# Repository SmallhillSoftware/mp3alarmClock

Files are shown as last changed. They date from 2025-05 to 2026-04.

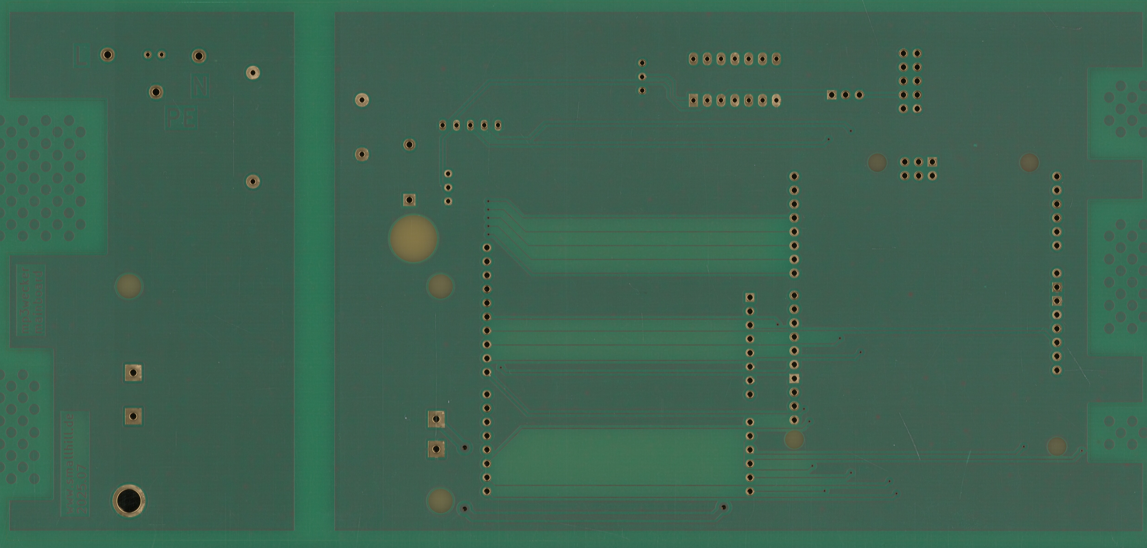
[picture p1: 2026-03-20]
pcb-layouts/mp3wecker_mainboard_endoberflaecheTop.jpg

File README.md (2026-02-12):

# mp3alarmClock
# S. Kleineberg / 2026                                  rev. (2025)1031 
***********************************************************************
The mp3alarmClock is an Arduino-Uno-based alarm clock that wakes you
up by playing 100 of your favourite MP3s stored on a Mico-SD-card.
The SD-card-handling and MP3-decoding and amplification is done using
an Adafruit-MP3-shield. The actual time is displayed on green 7-Segment-
LED-displays. The clock could be synchronized by a quarz crystal or
50Hz-power-frequency.
Details for the HW could be found at:
http://www.smallhill.de/html/hardware.html
***********************************************************************

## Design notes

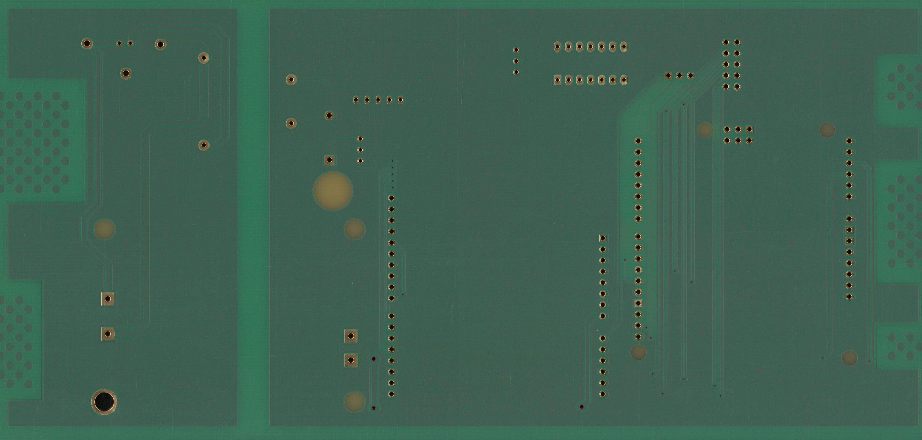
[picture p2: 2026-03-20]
pcb-layouts/mp3wecker_mainboard_endoberflaecheBottom.jpg

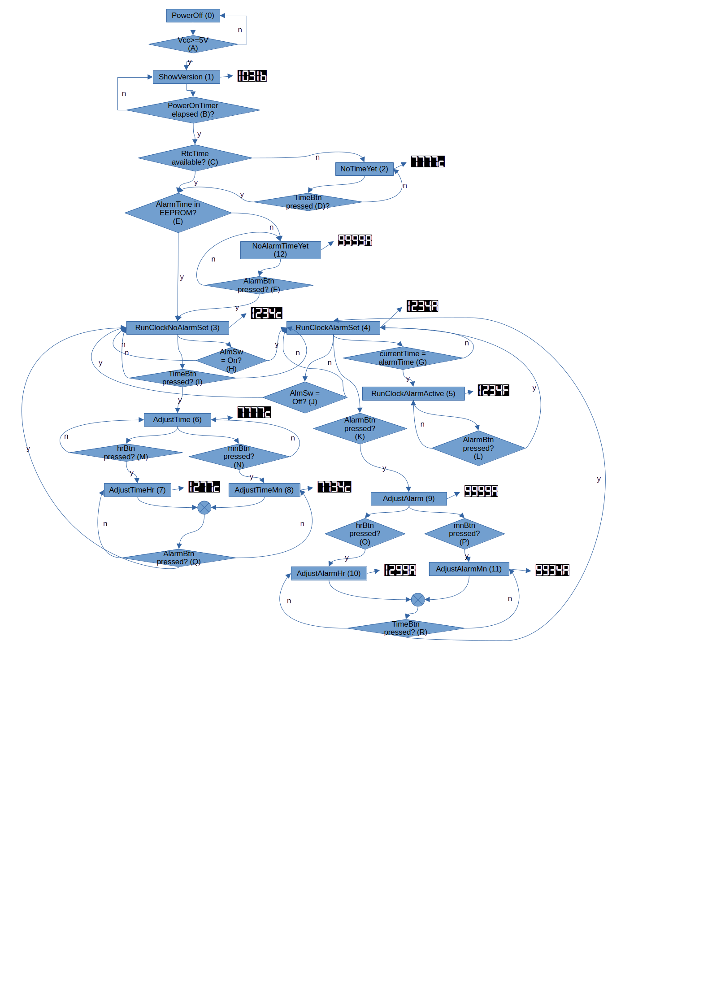
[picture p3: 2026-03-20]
documentation/statemachine_mp3wecker.png

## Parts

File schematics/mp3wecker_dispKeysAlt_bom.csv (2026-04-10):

# | Reference | Qty | Value | Footprint | DNP
1 | D1, D2, D3, D4, D5 | 5 | SC56-11GWA | mp3weckerLibrary:SA56kingbright
2 | D6, D7 | 2 | 3mmGN | LED_THT:LED_D3.0mm_IRBlack
3 | D8, D9 | 2 | 1N4148 | Diode_THT:D_DO-35_SOD27_P7.62mm_Horizontal
4 | J2 | 1 | Arduino | PCM_4ms_Connector:Pins_2x05_2.54mm_TH_Europower
5 | Q1, Q2, Q3, Q4, Q5, Q6 | 6 | BC337 | Package_TO_SOT_THT:TO-92L_HandSolder
6 | R1, R2, R3, R4, R5, R13, R14, R15 | 8 | 1k | Resistor_THT:R_Axial_DIN0207_L6.3mm_D2.5mm_P2.54mm_Vertical
7 | R6, R7, R8, R9, R10, R11 | 6 | 33k | Resistor_THT:R_Axial_DIN0207_L6.3mm_D2.5mm_P2.54mm_Vertical
8 | R12 | 1 | 250R | Resistor_THT:R_Axial_DIN0207_L6.3mm_D2.5mm_P2.54mm_Vertical
9 | R16, R17, R18, R19, R20, R21, R23 | 7 | 220R | Resistor_THT:R_Axial_DIN0207_L6.3mm_D2.5mm_P2.54mm_Vertical
10 | S1 | 1 | Alarm | r8c13_consCounter2:RACON12
11 | S2 | 1 | Time | r8c13_consCounter2:RACON12
12 | S3 | 1 | Hour+ | r8c13_consCounter2:RACON12
13 | S4 | 1 | Min+ | r8c13_consCounter2:RACON12
14 | SW1 | 1 | SW_Push_SPDT | PCM_4ms_Switch:Switch_Toggle_SPDT_SubMini
15 | U1 | 1 | 4511 | Package_DIP:CERDIP-16_W7.62mm_SideBrazed_LongPads_Socket
16 | U3 | 1 | MCP23008-xP | Package_DIP:DIP-18_W7.62mm
17 | U9 | 1 | 4017 | Package_DIP:DIP-16_W7.62mm_Socket_LongPads

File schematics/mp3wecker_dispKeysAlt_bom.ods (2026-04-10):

Referenz | Menge | Typ
D1, D2, D3, D4, D5 | 5 | SC56-11GWA
D6, D7 | 2 | LED, 3mm GN
D8, D9 | 2 | 1N4148
J2 | 1 | Arduino-Connector
Q1, Q2, Q3, Q4, Q5, Q6 | 6 | BC337
R1, R2, R3, R4, R5, R13, R14, R15 | 8 | 1k
R6, R7, R8, R9, R10, R11 | 6 | 33k
R12 | 1 | 250R
R16, R17, R18, R19, R20, R21, R23 | 7 | 220R
S1, S2, S3, S4 | 1 | RACON12
SW1 | 1 | SW_Push_SPDT
U1 | 1 | 4511, DIP-16
U3 | 1 | MCP23008-xP
U9 | 1 | 4017, DIP16

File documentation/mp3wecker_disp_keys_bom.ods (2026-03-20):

Referenz | Menge | Typ
D1, D2, D3, D4, D5 | 5 | SA56-11GWA
D6, D7 | 2 | LED, 3mmGN
J2 | 1 | Arduino-Connector
Q1, Q2, Q3, Q4, Q5, Q6 | 6 | BC327
R1, R2, R3, R4, R5, R15 | 6 | 1k
R6, R7, R8, R9, R10, R11 | 6 | 33k
R12, R13, R14 | 3 | 250R
RV1 | 1 | 50k, Bourns 3296W
S1, S2, S3, S4 | 1 | RACON12
SW1 | 1 | SW_Push_SPDT
U1 | 1 | D346D
U3 | 1 | MCP23008-xP
U9 | 1 | GAL16V8

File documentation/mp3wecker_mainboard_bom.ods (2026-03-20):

Referenz | Menge | Typ
A1 | 1 | Connector MP3-Shield
A2 | 1 | Connector Arduino UNO R3
D1 | 1 | 1N4001
J1, J3 | 2 | Conn_01x01_Socket
J2 | 1 | Arduino
J4 | 1 | N
J5 | 1 | ODROID-RTC
JP1 | 1 | 3er Jumper
JP2 | 1 | 2er Jumper
R1, R2 | 2 | 10k
T1 | 1 | Transformer_1P_1S
U1 | 1 | 4093, DIP14
U2 | 1 | EPS-15-7.5

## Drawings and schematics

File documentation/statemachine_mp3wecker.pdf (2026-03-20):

1031b

7777c

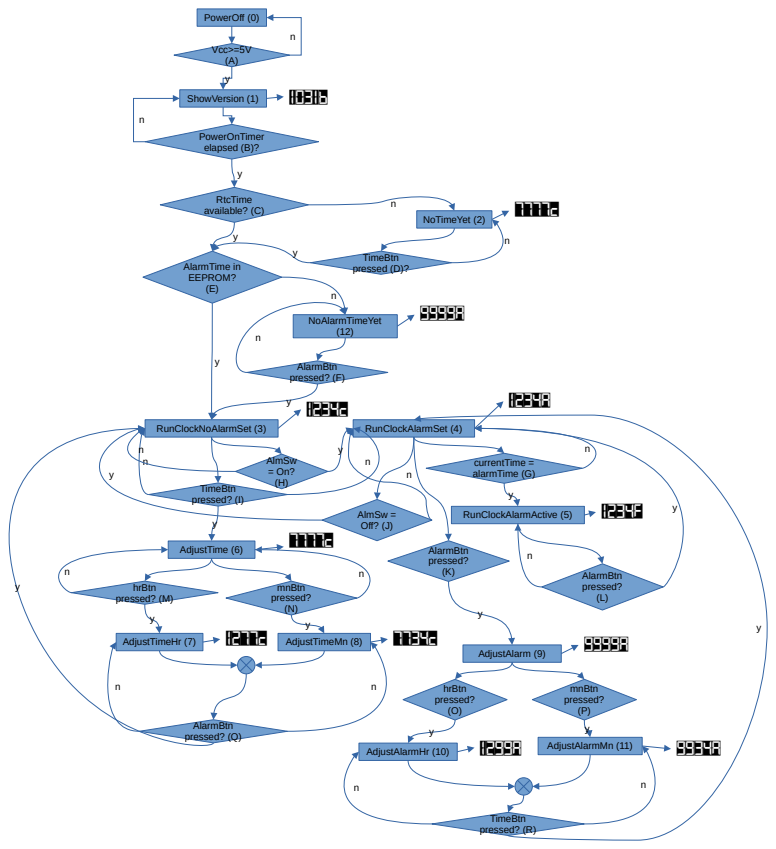
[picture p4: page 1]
PowerOff (0); ShowVersion (1); NoTimeYet (2); RunClockNoAlarmSet (3); AdjustTimeHr (7); AdjustTimeMn (8); AdjustAlarmHr (10); AdjustAlarmMn (11); RunClockAlarmSet (4); RunClockAlarmActive (5); Vcc>=5V (A); PowerOnTimer elapsed (B)?; TimeBtn pressed (D)?; AlarmBtn pressed? (F); AlarmTime in EEPROM? (E); RtcTime available? (C); AlmSw = On? (H); currentTime = alarmTime (G); AdjustTime (6); TimeBtn pressed? (I); hrBtn pressed? (M); mnBtn pressed? (N); AlarmBtn pressed? (Q); AlarmBtn pressed? (K)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

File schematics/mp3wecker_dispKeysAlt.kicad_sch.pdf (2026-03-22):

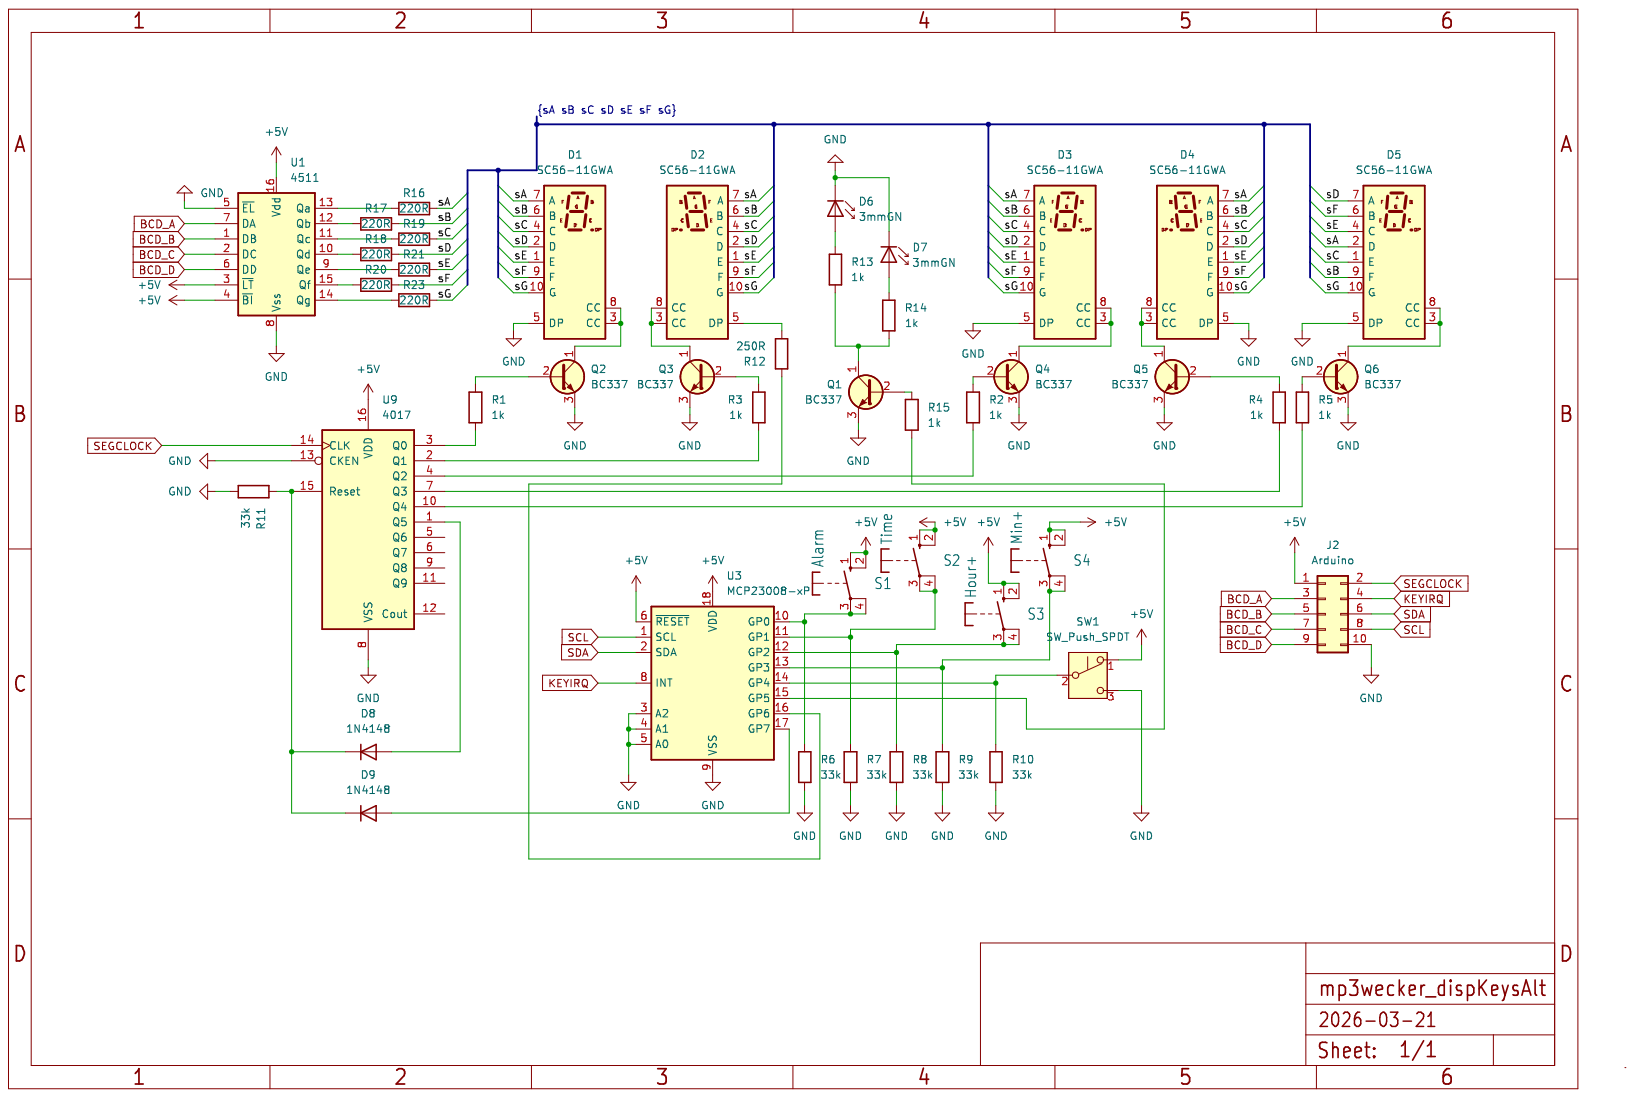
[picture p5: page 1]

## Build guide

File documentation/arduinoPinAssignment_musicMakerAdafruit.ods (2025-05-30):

valid for Arduino: | Uno Rev3
valid for shield: | Music Maker (Adafruit)
pin name | specific pin function | used pin direction for Arduino | shield pin name | explanation | comment
IO0 | RxD (UART)
IO1 | TxD (UART)
IO2 | INT0
IO3 | INT1 | input | DREQ (VS1053) | VS1053 data request IRQ
IO4 |  | output | CCS (SD) | SD card chip select
IO5
IO6 |  | output | DCS (VS1053) | VS1053 data select
IO7 |  | output | MCS (VS1053) | VS1053 chip select
IO8
IO9
IO10 | SS (SPI)
IO11 | MOSI (SPI) | output | MOSI (SD, VS1053)
IO12 | MISO (SPI) | input | MISO (SD, VS1053)
IO13 | SCK (SPI) | output | SCK (SD, VS1053)
AD0
AD1
AD2
AD3
AD4 | SDA (I2C)
AD5 | SCL (I2C)

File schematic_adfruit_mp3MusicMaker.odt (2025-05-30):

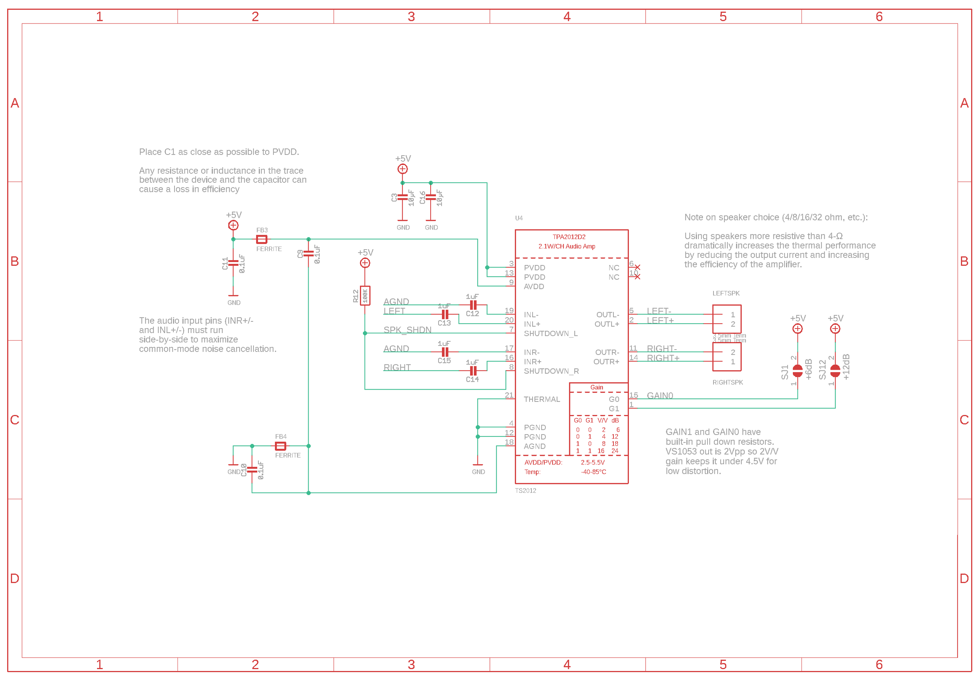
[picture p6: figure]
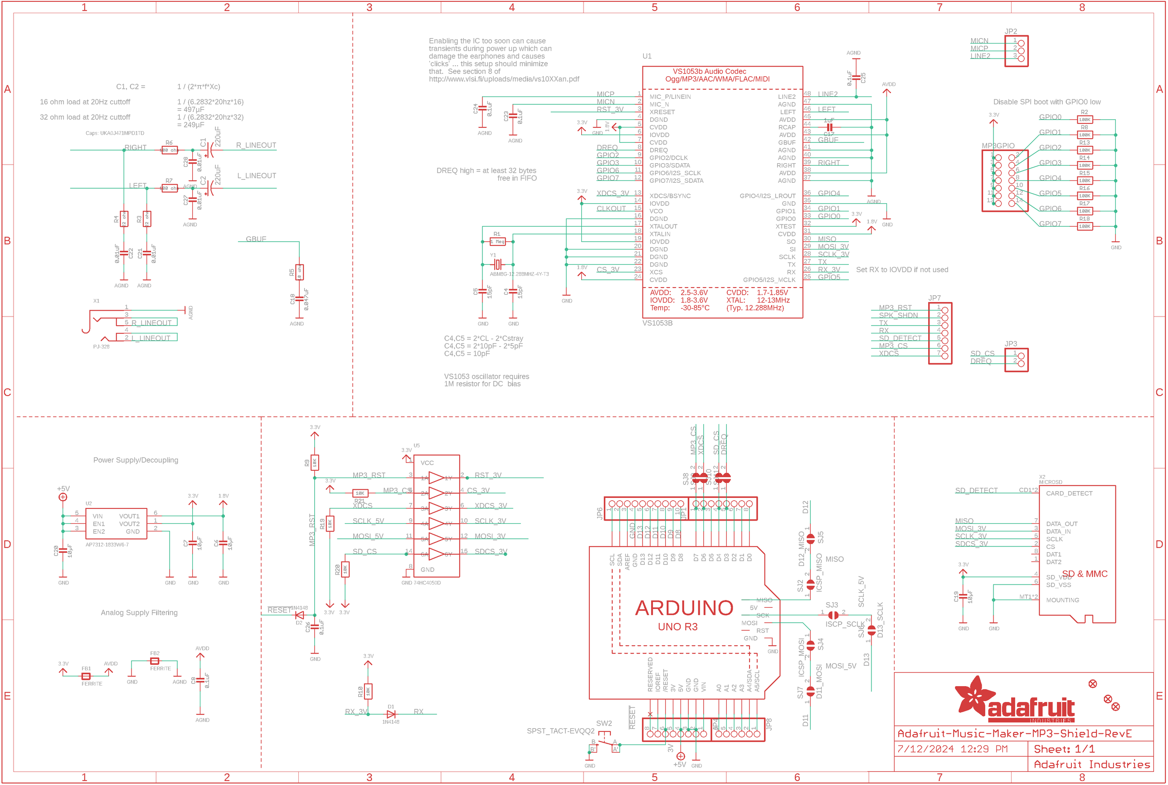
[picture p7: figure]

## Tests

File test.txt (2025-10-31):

Donnerstag 02.10.25 21:01 nach Smartphone Uhr eingestellt
ohne delay(100) in der loop
mit 61536 timer reload wert (2^16-4000).
Sonntag 05.10.25 18:30 Anzeige Uhr 17:09 also 90 Minuten zu spaet.
Neue SW mit Timerreloadwert 61540
Synchronisiert mit CD-Wecker um 18:37 am 05.10.25.
Aendert kaum etwas. Ist nach 1 Tag mindestens 20 min zu spaet.
Neue SW 2025.10.28 mit 5ms Timerwert nach
https://deepbluembedded.com/arduino-timer-calculator-code-generator/
Synchronisiert mit CD-Wecker am 28.10.25 21:43 (mp3wecker auf 21:45)
CD-Wecker am 29.10.25 21:02 (mp3Wecker auf 20:52)
Fehler -0.85%. Aus 5ms oder 5000µs werden damit 4957.1122µs. Timer Reload Wert 55621
SW 29.10.25
Synchronisiert mit CD-Wecker am 29.10.25 21:27 (mp3wecker auf 21:27)
Zeigt am 30.10.25 21:46 auf dem cdWecker und 21:48 auf dem mp3Wecker

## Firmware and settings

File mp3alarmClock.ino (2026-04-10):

/******************************************************************************
 * MP3ALARMCLOCK
 * Drives a 4-digit-7-Segment-LED-display, implements a quarz- or net-frequency
 * synced clock with possibility to set an alarm time
 * Plays MP3-files between 00.mp3 and 99.mp3 when the alarm time fires
 * www.smallhill.de 2025
 ******************************************************************************/
#include <EEPROM.h>
#include <SD.h>
#include <SPI.h>
#include <Adafruit_VS1053.h>
#include "MCP23008.h"

/******************************************************************************
 * globale Defines
 ******************************************************************************/
// These are the pins used for the music maker shield
#define VS1053RESETpin -1      // VS1053 reset pin (unused!)
#define VS1053CSpin     7      // VS1053 chip select pin (output)
#define VS1053DCSpin    6      // VS1053 Data/command select pin (output)
// These are common pins between breakout and shield
#define SDCARDCSpin     4      // Card chip select pin
// DREQ should be an Int pin, see http://arduino.cc/en/Reference/attachInterrupt
#define VS1053DREQpin   3      // VS1053 Data request, ideally an Interrupt pin
//#define D_RELOADvalFor20ms 25536
//#define D_RELOADvalFor2ms 61540
#define D_RELOADvalFor5ms 55621 //4957µs
#define D_mp3Clock 0
#define D_4511_4017 1
#if (D_mp3Clock)
  //pinning for for MP3-clock
  #define D_SEGCLOCKpin 0
  #define D_BCDApin 1
  #define D_BCDBpin 9
  #define D_BCDCpin 10
  #define D_BCDDpin A1
#else
  //pinning for Arduino Uno Adapter but not for MP3-clock
  #define D_SEGCLOCKpin 10
  #define D_BCDApin 1
  #define D_BCDBpin 2
  #define D_BCDCpin 9
  #define D_BCDDpin 0
#endif
#if (D_4511_4017)
  #define D_DISPSTATECLK 7 //L
  #define D_DISPSTATEALM 3 //E
  #define D_DISPSTATEACT 9 //stilisiertes Y
  #define D_DISPSTATEVER 4 //stilisiertes V
  #define D_DISPSTATE_TST2 5 //S
  #define D_DISPSTATE_TST3 5 //S
#else
  #define D_DISPSTATECLK 12 //C
  #define D_DISPSTATEALM 10 //A
  #define D_DISPSTATEACT 15 //F
  #define D_DISPSTATEVER 11 //b
  #define D_DISPSTATE_TST2 13 //d
  #define D_DISPSTATE_TST3 14 //e
#endif

#define D_PowerOff_State             0
#define D_ShowVersion_State          1
#define D_noTimeYet_State            2
#define D_RunClockNoAlarmSet_State   3
#define D_RunClockAlarmSet_State     4
#define D_RunClockAlarmActive_State  5
#define D_AdjustTime_State           6
#define D_AdjustTimeHr_State         7
#define D_AdjustTimeMn_State         8
#define D_AdjustAlarm_State          9
#define D_AdjustAlarmHr_State       10
#define D_AdjustAlarmMn_State       11
#define D_noAlarmTimeYet_State      12

//eeprom addresses
#define D_eepromAdrFileHandling      0
#define D_eepromAdrAlarmHr           1
#define D_eepromAdrAlarmMin          2


/******************************************************************************
 * globale Variablen
 ******************************************************************************/
Adafruit_VS1053_FilePlayer musicPlayer = 
  // create shield-example object!
  Adafruit_VS1053_FilePlayer(VS1053RESETpin, VS1053CSpin, VS1053DCSpin, VS1053DREQpin, SDCARDCSpin);

byte BT_mk_month = 4;
byte BT_mk_day = 10;

bool BL_setupFinished = false;

//clock variables
byte BT_currHr = 12;
byte BT_currMin = 34;
//alarm variables
byte BT_alarmHr = 0;
byte BT_alarmMin = 0;
//display variables
byte BT_dispHr = 0;
byte BT_dispMin = 0;
byte BT_dispState = 0;
//unsigned int UI_twentyMSecs = 0;
//unsigned int UI_twoMSecs = 0;
unsigned int UI_fiveMSecs = 0;
unsigned int UI_seconds = 0;

//display variables
int INT_digitToUpdate = 0;

//i2c-port-extender
MCP23008 MCP(0x20);

#define D_ALMBUTTON     0
#define D_SETTIMEBUTTON 1
#define D_HOURINCBUTTON 2
#define D_MININCBUTTON  3
#define D_ALMONBUTTON   4
#define D_MID_LEDS_OUT  5
#define D_D2_DP_OUT     6
#define D_OE_RESET_OUT  7
byte BT_buttonState = 0;
byte BT_prevButtonState = 0;
bool BL_midLedState = false;
unsigned long UL_currentButtonMillis = 0;
unsigned long UL_previousButtonMillis = 0;
#define D_minButtonPressDurationInMs 100

//state machine
byte BT_State = D_PowerOff_State;
byte BT_prevState;

//get time from battery backed-up RTC
bool B_timeFromRtc;
unsigned char UC_hourFromRtc = 0;
unsigned char UC_minuteFromRtc = 0;

//eeprom variables
unsigned char UC_filenumber = 0;
bool B_fileNrInEeprom;
unsigned char UC_storedAlarmHr  = 0;
bool B_alarmHrInEeprom;
unsigned char UC_storedAlarmMin = 0;
bool B_alarmMinInEeprom;

//file name for MP3-files to play in 8.3-format
char C_filename[12];

//indicator if currently MP3s are played
bool B_playMusic = false;

#define D_invertedAmpVolume 45

/******************************************************************************
 * Funktionen
 ******************************************************************************/
void initSegmentCounter(void)
{
  digitalWrite(D_SEGCLOCKpin, LOW);
  MCP.write1(D_OE_RESET_OUT, HIGH);
  #if (D_4511_4017)
    delay(100);
  #else
    for (int i=0; i<5; i++)
    {
      //Generiere 5 Pulse um alle D-flip-flops durchzutakten
      digitalWrite(D_SEGCLOCKpin, LOW);
      delay(50);
      digitalWrite(D_SEGCLOCKpin, HIGH);
      delay(50);
    }
  #endif
  //Reset fuer Segment-Counter zuruecknehmen
  MCP.write1(D_OE_RESET_OUT, LOW);
}


void writeBcdToSegPins(byte BT_givenNumber, byte BT_upperNibble)
{
byte BT_number;
  if (BT_upperNibble == 1)
  {
    BT_number = (byte)(BT_givenNumber / 10);
  }
  else if (BT_upperNibble == 2)
  {
    BT_number = BT_givenNumber;
  }
  else
  {
    BT_number = (byte)(BT_givenNumber % 10);
  }
  if ((BT_number & 1) == 1)
  {
    digitalWrite(D_BCDApin, HIGH);
  }
  else
  {
    digitalWrite(D_BCDApin, LOW);
  }
  if ((BT_number & 2) == 2)
  {
    digitalWrite(D_BCDBpin, HIGH);
  }
  else
  {
    digitalWrite(D_BCDBpin, LOW);
  }
  if ((BT_number & 4) == 4)
  {
    digitalWrite(D_BCDCpin, HIGH);
  }
  else
  {
    digitalWrite(D_BCDCpin, LOW);
  }
  if ((BT_number & 8) == 8)
  {
    digitalWrite(D_BCDDpin, HIGH);
  }
  else
  {
    digitalWrite(D_BCDDpin, LOW);
  }
}


void setup()
{
byte bt_eepromData;
  //Clock pin fuer Segment-Counter als Ausgang und Low setzen
  pinMode(D_SEGCLOCKpin, OUTPUT);
  digitalWrite(D_SEGCLOCKpin, LOW);
  //BCD-pins fuer D346 als Ausgaenge setzen
  pinMode(D_BCDApin, OUTPUT);
  digitalWrite(D_BCDApin, LOW);
  pinMode(D_BCDBpin, OUTPUT);
  digitalWrite(D_BCDBpin, LOW);
  pinMode(D_BCDCpin, OUTPUT);
  digitalWrite(D_BCDCpin, LOW);
  pinMode(D_BCDDpin, OUTPUT);
  digitalWrite(D_BCDDpin, LOW);

  //get file number from eeprom
  bt_eepromData = EEPROM.read(D_eepromAdrFileHandling);
  if ((bt_eepromData & 0x80) == 0x80)
  {
    B_fileNrInEeprom = true;
    UC_filenumber = (bt_eepromData & 0x7F);
    if (UC_filenumber > 99)
    {
      UC_filenumber = 99;
    }
  }
  else
  {
    B_fileNrInEeprom = false;
    UC_filenumber = 0;
  }

  //get alarm hour from eeprom
  bt_eepromData = EEPROM.read(D_eepromAdrAlarmHr);
  if ((bt_eepromData & 0x80) == 0x80)
  {
    B_alarmHrInEeprom = true;
    UC_storedAlarmHr = (bt_eepromData & 0x7F);
    if (UC_storedAlarmHr > 23)
    {
      B_alarmHrInEeprom = false;
      UC_storedAlarmHr = 0;
    }
  }
  else
  {
    B_alarmHrInEeprom = false;
    UC_storedAlarmHr = 0;
  }

  //get alarm minute from eeprom
  bt_eepromData = EEPROM.read(D_eepromAdrAlarmMin);
  if ((bt_eepromData & 0x80) == 0x80)
  {
    B_alarmMinInEeprom = true;
    UC_storedAlarmMin = (bt_eepromData & 0x7F);
    if (UC_storedAlarmMin > 59)
    {
      B_alarmMinInEeprom = false;
      UC_storedAlarmMin = 0;
    }
  }
  else
  {
    B_alarmMinInEeprom = false;
    UC_storedAlarmMin = 0;
  }

  //get time from battery backed-up RTC
  B_timeFromRtc = false;
  
  //Alle Interrupts deaktivieren
  noInterrupts();
  //
  INT_digitToUpdate = 0;
  //Bits von TCCR1A und TCCR1B loeschen
  TCCR1A = 0;
  TCCR1B = 0;
  //Laden des Zaehlerwertes
  TCNT1 = D_RELOADvalFor5ms;
  //Prescaler: 8
  TCCR1B |= (1 << CS11);
  //Enable timer overflow interrupt
  TIMSK1 |= (1 << TOIE1);
  //Alle Interrupts aktivieren
  interrupts();
      
  //MP3-Decoder initialisieren
  musicPlayer.begin();
  
  //SD-Karte initialisieren
  //SD_CS als parameter übergeben, da hier ChipSelect anders belegt
  SD.begin(SDCARDCSpin);
  
  // Set volume for left, right channels. lower numbers == louder volume!
  musicPlayer.setVolume(D_invertedAmpVolume,D_invertedAmpVolume);

  // This option uses a pin interrupt. No timers required! But DREQ
  // must be on an interrupt pin. For Uno/Duemilanove/Diecimilla
  // that's Digital #2 or #3
  // See http://arduino.cc/en/Reference/attachInterrupt for other pins
  // *** This method is preferred
  musicPlayer.useInterrupt(VS1053_FILEPLAYER_PIN_INT);

  Wire.begin();
  Wire.setWireTimeout(3000 /* us */, true /* reset_on_timeout */);
  MCP.begin(false);

  while(!(MCP.isConnected()))
  {
    //wait to be connected
    //verbindet aber nicht
  }
  
  //MCP.pinMode8(0x1F); //upper 3 bits are outputs
  MCP.pinMode1(D_ALMBUTTON, INPUT);
  MCP.pinMode1(D_SETTIMEBUTTON, INPUT);
  MCP.pinMode1(D_HOURINCBUTTON, INPUT);
  MCP.pinMode1(D_MININCBUTTON, INPUT);
  MCP.pinMode1(D_ALMONBUTTON, INPUT);
  MCP.pinMode1(D_MID_LEDS_OUT, OUTPUT);
  MCP.pinMode1(D_D2_DP_OUT, OUTPUT);
  MCP.pinMode1(D_OE_RESET_OUT, OUTPUT);
  
  MCP.setPolarity(D_ALMBUTTON, 0);
  MCP.setPolarity(D_SETTIMEBUTTON, 0);
  MCP.setPolarity(D_HOURINCBUTTON, 0);
  MCP.setPolarity(D_MININCBUTTON, 0);
  MCP.setPolarity(D_ALMONBUTTON, 0);
  MCP.setPolarity(D_MID_LEDS_OUT, 0);
  MCP.setPolarity(D_D2_DP_OUT, 0);
  MCP.setPolarity(D_OE_RESET_OUT, 0);

  MCP.setPullup(D_ALMBUTTON, 0);
  MCP.setPullup(D_SETTIMEBUTTON, 0);
  MCP.setPullup(D_HOURINCBUTTON, 0);
  MCP.setPullup(D_MININCBUTTON, 0);
  MCP.setPullup(D_ALMONBUTTON, 0);
  MCP.setPullup(D_MID_LEDS_OUT, 0);
  MCP.setPullup(D_D2_DP_OUT, 0);
  MCP.setPullup(D_OE_RESET_OUT, 0);
  
  initSegmentCounter(); //reset segment counter in GAL

  MCP.write1(D_MID_LEDS_OUT, HIGH); //klappt
  MCP.write1(D_D2_DP_OUT, HIGH);
  
  //signalize that the setup routine is finished
  BL_setupFinished = true;
}


ISR(TIMER1_OVF_vect)
{
  //START EXT-PIN-COUNT-IRQ
  //code to be executed when setup-routine is finished only
  if (BL_setupFinished)
  {
    //1sec passed
    if (UI_fiveMSecs == 200)
    {
      UI_fiveMSecs = 0;
      UI_seconds++;
      if (BL_midLedState == false)
      {
        BL_midLedState = true;
      }
      else
      {
        BL_midLedState = false;
      }
    }
    //1 minute passed, 200 occurrences of 5ms = 1sec and 60 of them means 1 min
    if (UI_seconds == 60)
    {
      UI_seconds = 0;
      if (BT_currMin < 59)
      {
        BT_currMin++;
      } //if (BT_currMin < 59)
      else
      {
        BT_currMin = 0;
        if (BT_currHr < 23)
        {
          BT_currHr++;
        } //if (BT_currHr < 23)
        else
        {
          BT_currHr = 0;
        } //else of if (BT_currHr < 23)
      } //else of if (BT_currMin < 59)
    } //if (UI_twoMSecs == (500 * 60))

    //write value to port pin
    digitalWrite(D_SEGCLOCKpin, LOW);
    if (INT_digitToUpdate == 0)
    {
      #if (D_4511_4017)
        writeBcdToSegPins(BT_dispHr, 0);
      #else
        writeBcdToSegPins(BT_dispHr, 1);
      #endif
      INT_digitToUpdate = 1;
    } //if (INT_digitToUpdate == 0)
    else if (INT_digitToUpdate == 1)
    {
      #if (D_4511_4017)
        writeBcdToSegPins(BT_dispMin, 1);
      #else
        writeBcdToSegPins(BT_dispHr, 0);
      #endif
      INT_digitToUpdate = 2;
    } //else if (INT_digitToUpdate == 1)
    else if (INT_digitToUpdate == 2)
    {
      #if (D_4511_4017)
        writeBcdToSegPins(BT_dispMin, 0);
      #else
        writeBcdToSegPins(BT_dispMin, 1);
      #endif
      INT_digitToUpdate = 3;
    } //else if (INT_digitToUpdate == 2)
    else if (INT_digitToUpdate == 3)
    {
      #if (D_4511_4017)
        writeBcdToSegPins(BT_dispState, 2);
      #else
        writeBcdToSegPins(BT_dispMin, 0);
      #endif
      INT_digitToUpdate = 4;
    } //else if (INT_digitToUpdate == 3)
    else if (INT_digitToUpdate == 4)
    {
      #if (D_4511_4017)
        writeBcdToSegPins(BT_dispHr, 1);
      #else
        writeBcdToSegPins(BT_dispState, 2);
      #endif
      INT_digitToUpdate = 0;
    } //else if (INT_digitToUpdate == 4)
    //write value to port pin
    digitalWrite(D_SEGCLOCKpin, HIGH);
    //
    UI_fiveMSecs++;
  } //if (BL_setupFinished)
  //reload counter value to make the IRQ firing again, always necessary independent from setup finished or not
  TCNT1 = D_RELOADvalFor5ms;
  //END EXT-PIN-COUNT-IRQ  
}

void loop()
{
unsigned int cntr = 0;
//build file name
sprintf(C_filename, "/%02d.mp3", UC_filenumber);
  
byte bt_eepromData;
  if (BL_midLedState == true)
  {
    MCP.write1(D_D2_DP_OUT, LOW);
  }
  else
  {
    MCP.write1(D_D2_DP_OUT, HIGH);
  }
  //read in buttons
  UL_currentButtonMillis = millis();
  BT_buttonState = 0;
  if ((UL_currentButtonMillis - UL_previousButtonMillis) >= D_minButtonPressDurationInMs)
  {
    if (MCP.read1(D_ALMBUTTON) == HIGH)
    {
      BT_buttonState = BT_buttonState | (byte)(((byte)(1 << D_ALMBUTTON)) & 0xFF);
    }
    if (MCP.read1(D_SETTIMEBUTTON) == HIGH)
    {
      BT_buttonState = BT_buttonState | (byte)(((byte)(1 << D_SETTIMEBUTTON)) & 0xFF);
    }
    if (MCP.read1(D_HOURINCBUTTON) == HIGH)
    {
      BT_buttonState = BT_buttonState | (byte)(((byte)(1 << D_HOURINCBUTTON)) & 0xFF);
    }
    if (MCP.read1(D_MININCBUTTON) == HIGH)
    {
      BT_buttonState = BT_buttonState | (byte)(((byte)(1 << D_MININCBUTTON)) & 0xFF);
    } 
    //update time stamp for pressing
    UL_previousButtonMillis += D_minButtonPressDurationInMs;
  } //end of if ((UL_currentButtonMillis - UL_previousButtonMillis) >= D_minButtonPressDurationInMs)
  if (MCP.read1(D_ALMONBUTTON) == HIGH)
  {
    BT_buttonState = BT_buttonState | (byte)(((byte)(1 << D_ALMONBUTTON)) & 0xFF);
  }
  
  //state machine
  switch (BT_State)
  {
    case D_PowerOff_State:
      BT_prevState = BT_State; //store previous state
      BT_State = D_ShowVersion_State;
      break; //D_PowerOff_State
    case D_ShowVersion_State:
      BT_dispHr = BT_mk_month;
      BT_dispMin = BT_mk_day;
      BT_dispState = D_DISPSTATEVER;
      delay(3000); //condition to change to next state
      if (B_timeFromRtc == true)
      {
        if ((B_alarmHrInEeprom == true) && (B_alarmMinInEeprom == true))
        {
          BT_State = D_RunClockNoAlarmSet_State;
        }
        else
        {
          BT_State = D_noAlarmTimeYet_State;
        }
      }
      else
      {
        BT_State = D_noTimeYet_State;
      }
      break; //D_ShowVersion_State
    case D_noTimeYet_State:
      BT_dispHr = 77;
      BT_dispMin = 77;
      BT_dispState = D_DISPSTATECLK;
      if ((BT_buttonState & (1 << D_SETTIMEBUTTON)) == (1 << D_SETTIMEBUTTON))
      {
        if ((B_alarmHrInEeprom == true) && (B_alarmMinInEeprom == true))
        {
          BT_State = D_RunClockNoAlarmSet_State;
        }
        else
        {
          BT_State = D_noAlarmTimeYet_State;
        }
      }
      break; //D_noTimeYet_State
    case D_noAlarmTimeYet_State:
      BT_dispHr = 99;
      BT_dispMin = 99;
      BT_dispState = D_DISPSTATEALM;
      if ((BT_buttonState & (1 << D_ALMBUTTON)) == (1 << D_ALMBUTTON))
      {
        BT_State = D_RunClockNoAlarmSet_State;
      }
      break; //D_noAlarmTimeYet_State
    case D_RunClockNoAlarmSet_State:
      BT_dispHr = BT_currHr;
      BT_dispMin = BT_currMin;
      BT_dispState = D_DISPSTATECLK;
      //wenn ich diese Bedingung rausnehme dann wechselt er nicht mehr in den Einstellmodus
      //wenn ich dann aber den Alarmzustand aktiviere wechselt er in den Einstellmodus und
      //alles blinkt
      if ((BT_buttonState & (1 << D_SETTIMEBUTTON)) == (1 << D_SETTIMEBUTTON))
      {
        BT_prevState = BT_State; //store previous state
        BT_State = D_AdjustTime_State;
      }
      else if ((BT_buttonState & (1 << D_ALMONBUTTON)) == (1 << D_ALMONBUTTON))
      {
        BT_State = D_RunClockAlarmSet_State;
      }
      break; //D_RunClockNoAlarmSet_State
    case D_RunClockAlarmSet_State:
      BT_dispHr = BT_currHr;
      BT_dispMin = BT_currMin;
      BT_dispState = D_DISPSTATEALM;
      if ((BT_currHr == BT_alarmHr) && (BT_currMin == BT_alarmMin))
      {
        BT_State = D_RunClockAlarmActive_State;
      }
      else if ((BT_buttonState & (1 << D_ALMBUTTON)) == (1 << D_ALMBUTTON))
      {
        BT_prevState = BT_State; //store previous state
        BT_State = D_AdjustAlarm_State; 
      }
      else if (!((BT_buttonState & (1 << D_ALMONBUTTON)) == (1 << D_ALMONBUTTON)))
      {
        BT_State = D_RunClockNoAlarmSet_State;
      }
      break; //D_RunClockAlarmSet_State
    case D_RunClockAlarmActive_State:
      BT_dispHr = BT_currHr;
      BT_dispMin = BT_currMin;
      BT_dispState = D_DISPSTATEACT;
      //play mp3s
      if ((BT_buttonState & (1 << D_ALMBUTTON)) == (1 << D_ALMBUTTON))
      {
        bt_eepromData = UC_filenumber + 0x80;
        EEPROM.update(D_eepromAdrFileHandling, bt_eepromData);
        BT_State = D_RunClockAlarmSet_State;
      }
      break; //D_RunClockAlarmActive_State
    case D_AdjustTime_State:
      BT_dispHr = 77;
      BT_dispMin = 77;
      BT_dispState = D_DISPSTATECLK;
      if ((BT_buttonState & (1 << D_HOURINCBUTTON)) == (1 << D_HOURINCBUTTON))
      {
        BT_State = D_AdjustTimeHr_State;
      }
      else if ((BT_buttonState & (1 << D_MININCBUTTON)) == (1 << D_MININCBUTTON))
      {
        BT_State = D_AdjustTimeMn_State;
      }
      else if ((BT_buttonState & (1 << D_ALMBUTTON)) == (1 << D_ALMBUTTON))
      {
        if (BT_prevState == D_RunClockAlarmSet_State)
        {
          BT_State = D_RunClockAlarmSet_State;
        }
        else
        {
          BT_State = D_RunClockNoAlarmSet_State;
        }
      }
      break; //D_AdjustTime_State
    case D_AdjustTimeHr_State:
      BT_dispHr = BT_currHr;
      BT_dispMin = 77;
      BT_dispState = D_DISPSTATECLK;
      if ((BT_buttonState & (1 << D_HOURINCBUTTON)) == (1 << D_HOURINCBUTTON))
      {
        if (BT_currHr < 23)
        {
          BT_currHr++;
        }
        else
        {
          BT_currHr = 0;
        }
      }
      else if ((BT_buttonState & (1 << D_SETTIMEBUTTON)) == (1 << D_SETTIMEBUTTON))
      {
        BT_State = D_AdjustTime_State;
      }
      break; //AdjustTimeHr_State
    case D_AdjustTimeMn_State:
      BT_dispHr = 77;
      BT_dispMin = BT_currMin;
      BT_dispState = D_DISPSTATECLK;
      if ((BT_buttonState & (1 << D_MININCBUTTON)) == (1 << D_MININCBUTTON))
      {
        if (BT_currMin < 59)
        {
          BT_currMin++;
        }
        else
        {
          BT_currMin = 0;
        }
      }
      else if ((BT_buttonState & (1 << D_SETTIMEBUTTON)) == (1 << D_SETTIMEBUTTON))
      {
        BT_State = D_AdjustTime_State;
      }
      break; //D_AdjustTimeMn_State
    case D_AdjustAlarm_State:
      BT_dispHr = 99;
      BT_dispMin = 99;
      BT_dispState = D_DISPSTATEALM;
      //ob ich diese Bedingung rauskommentiere oder drinlasse macht keinen Unterschied
      //er wechselt in den Einstell-Flacker-Modus
      if ((BT_buttonState & (1 << D_HOURINCBUTTON)) == (1 << D_HOURINCBUTTON))
      {
        BT_State = D_AdjustAlarmHr_State;
      }
      //ob ich diese Bedingung rauskommentiere oder drinlasse macht keinen Unterschied
      //er wechselt in den Einstell-Flacker-Modus
      else if ((BT_buttonState & (1 << D_MININCBUTTON)) == (1 << D_MININCBUTTON))
      {
        BT_State = D_AdjustAlarmMn_State;
      }
      //wenn ich diese Bedingungs auskommentiere wechselt er nicht mehr in den
      //Einstell-Flacker-Modus
      else if ((BT_buttonState & (1 << D_SETTIMEBUTTON)) == (1 << D_SETTIMEBUTTON))
      {
        //write Alarm Hour and Minute to EEPROM
        bt_eepromData = BT_alarmHr + 0x80;
        EEPROM.update(D_eepromAdrAlarmHr, bt_eepromData);
        bt_eepromData = BT_alarmMin + 0x80;
        EEPROM.update(D_eepromAdrAlarmMin, bt_eepromData);
        if (BT_prevState == D_RunClockAlarmSet_State)
        {
          BT_State = D_RunClockAlarmSet_State;
        }
        else
        {
          BT_State = D_RunClockNoAlarmSet_State;
        }
      }
      break; //D_AdjustAlarm_State
    case D_AdjustAlarmHr_State:
      BT_dispHr = BT_alarmHr;
      BT_dispMin = 99;
      BT_dispState = D_DISPSTATEALM;
      if ((BT_buttonState & (1 << D_HOURINCBUTTON)) == (1 << D_HOURINCBUTTON))
      {
        if (BT_alarmHr < 23)
        {
          BT_alarmHr++;
        }
        else
        {
          BT_alarmHr = 0;
        }
      }
      else if ((BT_buttonState & (1 << D_ALMBUTTON)) == (1 << D_ALMBUTTON))
      {
        BT_State = D_AdjustAlarm_State;
      }
      break; //D_AdjustAlarmHr_State
    case D_AdjustAlarmMn_State:
      BT_dispHr = 99;
      BT_dispMin = BT_alarmMin;
      BT_dispState = D_DISPSTATEALM;
      if ((BT_buttonState & (1 << D_MININCBUTTON)) == (1 << D_MININCBUTTON))
      {
        if (BT_alarmMin < 59)
        {
          BT_alarmMin++;
        }
        else
        {
          BT_alarmMin = 0;
        }
      }
      else if ((BT_buttonState & (1 << D_ALMBUTTON)) == (1 << D_ALMBUTTON))
      {
        BT_State = D_AdjustAlarm_State;
      }
      break; //D_AdjustAlarmMn_State
    default:
      break;
  }
  if (BT_State == D_RunClockAlarmActive_State)
  {
    if (!B_playMusic)
    {
      musicPlayer.startPlayingFile(C_filename);
    } //if (!B_playMusic)
    B_playMusic = musicPlayer.playingMusic;
    if (!B_playMusic)
    {
      if (UC_filenumber < 99)
      {
        UC_filenumber++;
      }
    	else
    	{
        UC_filenumber = 0;
    	}
    } //if (!B_playMusic)
  } //if (BT_State == D_RunClockAlarmActive_State)
  else
  {
    if (musicPlayer.playingMusic)
    {
      musicPlayer.stopPlaying();
    }
  }
}

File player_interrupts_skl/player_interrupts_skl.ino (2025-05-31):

/*************************************************** 
  This is an example for the Adafruit VS1053 Codec Breakout

  Designed specifically to work with the Adafruit VS1053 Codec Breakout 
  ----> https://www.adafruit.com/products/1381

  Adafruit invests time and resources providing this open source code, 
  please support Adafruit and open-source hardware by purchasing 
  products from Adafruit!

  Written by Limor Fried/Ladyada for Adafruit Industries.  
  BSD license, all text above must be included in any redistribution
 ****************************************************/

// include SPI, MP3 and SD libraries
#include <EEPROM.h>
#include <SPI.h>
#include <Adafruit_VS1053.h>
#include <SD.h>

// These are the pins used for the music maker shield
#define SHIELD_RESET  -1      // VS1053 reset pin (unused!)
#define SHIELD_CS     7      // VS1053 chip select pin (output)
#define SHIELD_DCS    6      // VS1053 Data/command select pin (output)

// These are common pins between breakout and shield
#define CARDCS 4     // Card chip select pin
// DREQ should be an Int pin, see http://arduino.cc/en/Reference/attachInterrupt
#define DREQ 3       // VS1053 Data request, ideally an Interrupt pin

Adafruit_VS1053_FilePlayer musicPlayer = 
  // create shield-example object!
  Adafruit_VS1053_FilePlayer(SHIELD_RESET, SHIELD_CS, SHIELD_DCS, DREQ, CARDCS);


////
char filename[11];

//Zähler für Dateien
unsigned char filenumber = 0;

bool bPlayMusic = false;
int  iEeepromAdrFileHandling = 0;
bool bFileNrInEeprom;
byte eepromData;

void setup()
{
  eepromData = EEPROM.read(iEeepromAdrFileHandling);
  if ((eepromData & 0x80) == 0x80)
  {
    bFileNrInEeprom = true;
    filenumber = (eepromData & 0x7F);
    if (filenumber > 99)
    {
      filenumber = 99;
    }
  }
  else
  {
    bFileNrInEeprom = false;
    filenumber = 0;
  }

  Serial.begin(9600);
  Serial.println("Adafruit VS1053 Library Test");

  // initialise the music player
  if (! musicPlayer.begin()) { // initialise the music player
     Serial.println(F("Couldn't find VS1053, do you have the right pins defined?"));
     while (1);
  }
  Serial.println(F("VS1053 found"));

  if (!SD.begin(CARDCS)) {
    Serial.println(F("SD failed, or not present"));
    while (1);  // don't do anything more
  }
  Serial.println("SD OK!");
  
  // Set volume for left, right channels. lower numbers == louder volume!
  musicPlayer.setVolume(20,20);

  // This option uses a pin interrupt. No timers required! But DREQ
  // must be on an interrupt pin. For Uno/Duemilanove/Diecimilla
  // that's Digital #2 or #3
  // See http://arduino.cc/en/Reference/attachInterrupt for other pins
  // *** This method is preferred
  if (! musicPlayer.useInterrupt(VS1053_FILEPLAYER_PIN_INT))
    Serial.println(F("DREQ pin is not an interrupt pin"));
}

void loop() {
  char outputstring[100];

  //build file name
  sprintf(filename, "/%02d.mp3", filenumber);

  if (!bPlayMusic)
  {
    // Start playing a file, then we can do stuff while waiting for it to finish
    if (! musicPlayer.startPlayingFile(filename))
    {
      sprintf(outputstring, "Could not open file %s", filename);
      Serial.println(outputstring);
      while(1);
    }
    else
    {
      sprintf(outputstring, "Started playing file:%s", filename);
      Serial.println(outputstring);
    }
    // file is now playing in the 'background' so now's a good time
    // to do something else like handling LEDs or buttons :)
  }
  
  bPlayMusic = musicPlayer.playingMusic;
  
  if (!bPlayMusic)
  {
    if (filenumber < 99)
    {
      filenumber++;
      eepromData = filenumber + 0x80;
      EEPROM.update(iEeepromAdrFileHandling, eepromData);
    }
    else
    {
      filenumber = 0;
    }
  }
}

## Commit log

2025-03-20 Funktioniert fast, SEGCLOCK-pin muss von RX-Pin verlegt werden.
2025-03-21 Anzeige steht jetzt, allerdings ist die Positionierung zufaellig. Aktualisierung alle 5ms.
2025-04-01 Abfrage der Tasten über MCP23008 implementiert und funktioniert.
2025-04-02 1te Version mit Statemachine und Tastenabfrage, Statemachine nicht komplett.
2025-04-27 Arduino-Application-SW: 20250426, GAL:digcntrb 20250421
2025-05-30 Erste Version mit Adafruit Music Maker die 00.mp3 bis 99.mp3 in Schleife abspielt
    [arduinoPinAssignment_asa1elv.ods, arduinoPinAssignment_mp3weckerdisp.ods, arduinoPinAssignment_musicMakerAdafruit.ods]
2025-05-31 Zweite Version mit Adafruit Music Maker die 00.mp3 bis 99.mp3 in Schleife abspielt, aber immer im EEPROM die naechste zu spielende Datei abspeichert und beim Power-on-reset aus dem EEPROM liest.
    [player_interrupts_skl.ino]
2025-08-03 1st version with Adafruit MP3-shield (VS1053), LED-driver and MCP23008-driver integrated, but not working.
    [mp3alarmClock.ino]
2025-08-26 Eine Version die keine Uhrzeit mehr anzeigt sondern wild im Einstellmodus hochzaehlt.
2025-08-26 Erlaubt keine Einstellung von Zeit und Alarm laeuft aber sauber nach einem Hardreset, ohne Runterladen der SW.
2025-08-28 Uhr funktioniert jetzt direkt am Arduino Uno.
    [gitCommits.ods]
2025-09-28 Uhr laeuft zu langsam 20min minus in 18 Stunden, Musik wird zu laut wiedergegeben, Wiedergabe laesst sich nicht stoppen.
    [gitCommits.ods]
2025-10-02 Uhr laeuft zu langsam 30min minus in 24 Stunden, 60min minus in 48 Stunden, 90min minus in 72 Stunden, Musik wird immer noch etwas zu laut wiedergegeben, Wiedergabe stopptjetzt.
2025-10-05 Uhr laeuft zu langsam 90min in ca. 72h. delay raus aus main loop, timer wert auf 61536
2025-10-28 Versuche mit verschiedenen Timer Reload Werten bei 2ms
2025-10-31 Versuche mit verschiedenen Timer Reload Werten bei 5ms
2026-03-20 Passende HW-Dokumente ergaenzt.
    [arduinoPinAssignment_asa1elv.ods, arduinoPinAssignment_mp3weckerdisp.ods, arduinoPinAssignment_musicMakerAdafruit.ods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]
2026-03-22 Kicad-Projektdateien ergaenzt, alternativer Displaytreiber
    [mp3wecker_dispKeysAlt.kicad_pcb, mp3wecker_dispKeysAlt.kicad_sch]
2026-04-10 Erste Version mit alternativem Display
    [mp3wecker_dispKeysAlt.kicad_pcb, mp3wecker_dispKeysAlt.kicad_sch, mp3wecker_dispKeysAlt_bom.csv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]
